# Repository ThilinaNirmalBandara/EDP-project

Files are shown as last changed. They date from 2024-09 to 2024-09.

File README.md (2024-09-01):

This is about our 2nd semester engineering design project at the University of Moratuwa, Faculty of Electronic and Telecommunication Engineering.
We have designed a mini portable UPS that can output 9 V and 12 V simultaneously. Key features include a battery level indicator, mode indicator, 
and automatic switching between power modes.

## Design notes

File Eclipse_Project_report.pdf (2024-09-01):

# Mini UPS for WiFi Routers

## By Team ECLIPSE

# Contents

Contents | 1

1

## 1.Project Description

Our project aims to develop a mini-uninterruptible power supply (UPS) specifically designed for WiFi routers. This mini UPS will ensure uninterrupted internet connectivity during power outages by providing backup power to the router. Additionally, it will include features such as battery level indication and a charging indicator.

Main features

- Backup Power for WiFi Routers: The mini UPS will provide backup power to WiFi routers during power outages, ensuring uninterrupted internet connectivity up to 6 hours.
- Battery Level Indication: A built-in battery level indicator will display the remaining battery capacity, allowing users to monitor the UPS’s status and plan accordingly.
- LED Indicator: The UPS will include LED indicators to notify users whether the output is connected to main power or battery power.

## 2.Technical Feasibility

Input Voltage

- 12V DC

Output Voltage

- 9V / 12V DC

Voltage Regulation

- Buck Converter: Reduces input voltage to 8.5 V for battery charging.
- Boost Converter: Steps up voltage to 12V output.
- Additional Buck Converter: Provides 9V output.

Charging Functionality

- Utilizes buck converter to regulate input voltage to 8.5 V for charging the battery pack.
- Utilizes a BMS board to ensure safety of battery pack.

Battery Pack

- Capacity: 6400 mAh 7.4 V
- Configuration: 2 series 2 parallel (3200 mAh 3.7 V each)
- Charging Method: Constant voltage charging with current limiting

Components specification

- IRF9530 power MOSFET: Fast swithcing action
- 1N5822 diodes : Over voltage protection(Peak Reverse voltage 40 V) , Low forward voltage drop (0.525 V) , High frequency operation , Low power loss

Conversion Efficiency

- Greater than 90%
Mini UPS | 2 | ECLIPSE

Protection Features

- Overvoltage Protection
- Overcurrent Protection
- Reverse Polarity Protection

Dimensions

- 12cm x 9cm x 6cm [Length x Width x Height]

Enclosure Material

- PLA

Indicator LEDs

- AC Power mode indicator
- Battery mode indicator
- Battery level indicator

Connectors

- Input: DC female barrel jack (5.5 x 2.5 mm)
- Output: 2 x DC female barrel jack (5.5 x 2.5 mm)

## 3.Product Architecture

Input

- Would be taken from the 12V adapter.
- Is directly connected to the buck converter that steps down the voltage to 8.5V.

Output

- Depending on the user’s requirement, output can be taken as either 9V or 12V.
- Would be taken from the Buck-Boost converter.
- 12V - From the Boost converter.
- 9V - Above 12V will be further stepped down and taken from the Buck converter.

Indicators

- Two LEDs - Indicate the mode the UPS is working on (Direct mode or using the battery).
- LED screen - Indicates the battery level of the UPS.
Mini UPS | 3 | ECLIPSE

How to Work with this UPS

- **Powering the UPS:**

– Use the adapter that comes with your WiFi router.

– Plug the adapter into the input of the UPS.

– Use the male-to-male DC cable provided to connect the output of the UPS to your router.

- **Dual Router Setup:**

– If you need to power two routers simultaneously, use a separate adapter that provides at least 3A of current as the input to the UPS.

- **Front Panel Indicators:**

– The green LED indicates that the UPS is in battery mode.

– The red LED indicates that the UPS is in mains power mode.

– The LED screen displays the current battery level.

- **Switches:**

– The switch located at the bottom of the LED screen allows you to turn the screen on and off.

– The main switch controls the power output of the UPS, turning it on or off as needed.

## 4.Schematic

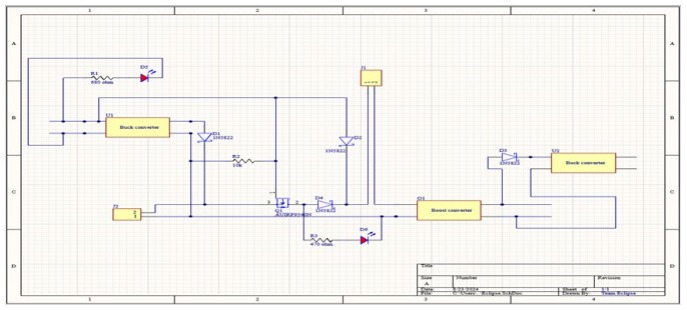
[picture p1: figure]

## 5.Sketches of the Product Enclosure

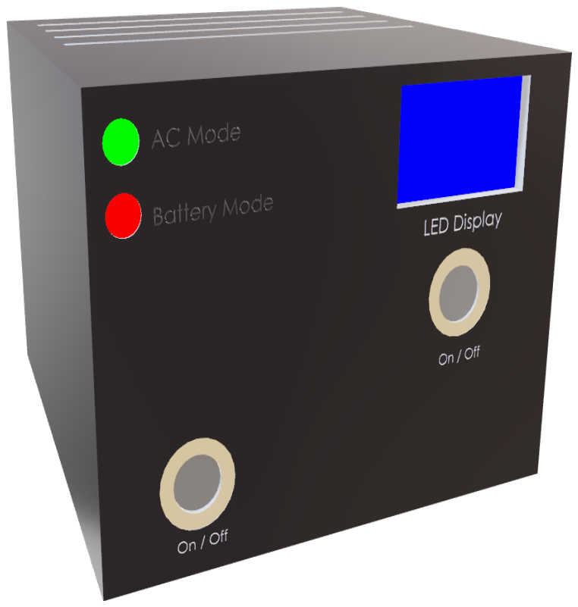
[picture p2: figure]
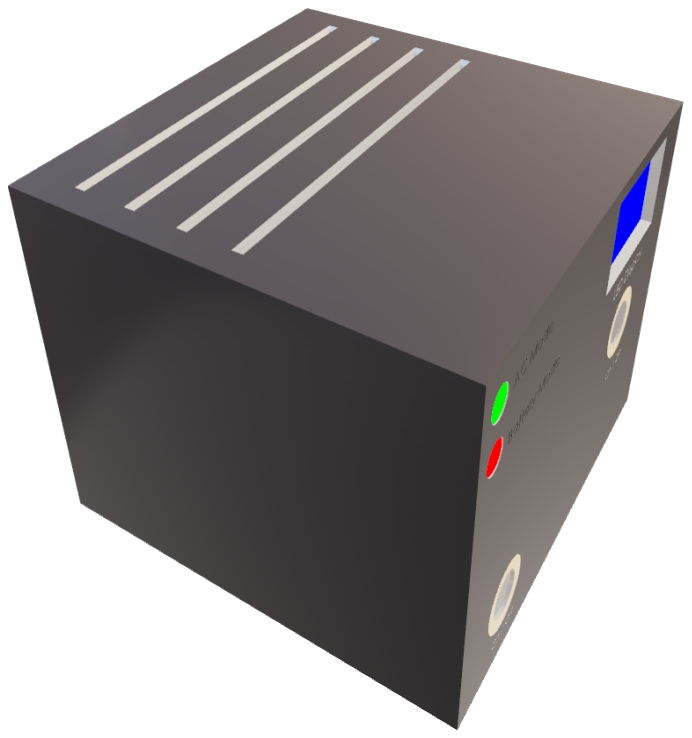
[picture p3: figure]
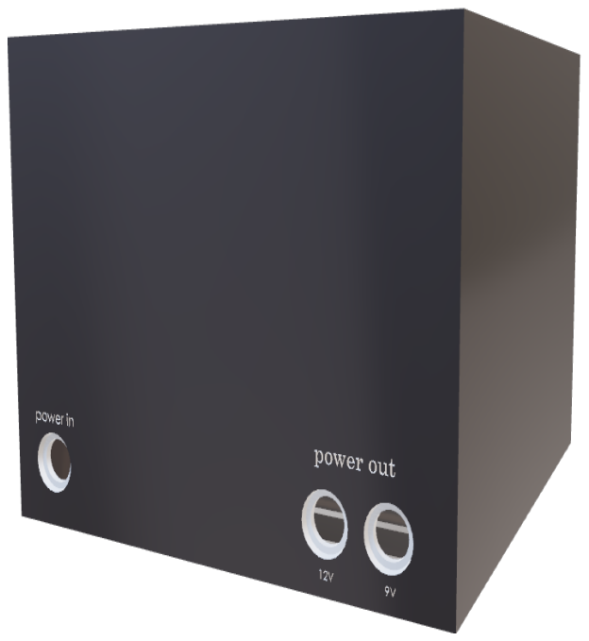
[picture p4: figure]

Mini UPS | 4 | ECLIPSE

## 6.PCB Design

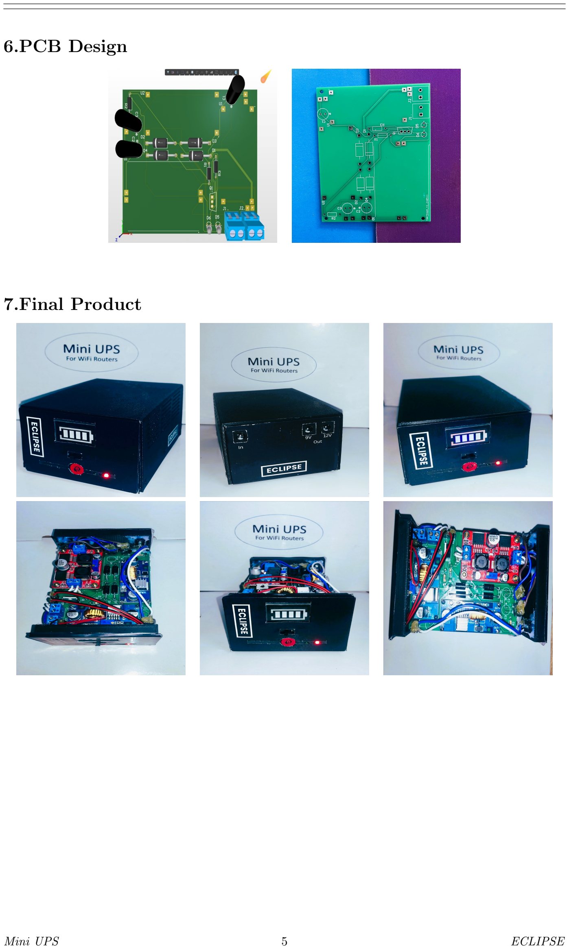
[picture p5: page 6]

## 7.Final Product

Mini UPS | 5 | ECLIPSE

## 8.Project Budget

Component | Description | Unit price | Price
Buck converter * 2 | Xl4015 | Rs.320.00 | Rs.640.00
Boost converter | LM2596 LM2577 | Rs.1120.00 | Rs.1120.00
BMS module | 2s,5A | Rs.230.00 | Rs.230.00
Batteries * 4 | 3.7V , 3200mAh | Rs.600.00 | Rs.2400.00
Other components | diodes, MOSFET, Resistors, LEDs | | Rs.600.00
Enclosure | | | Rs.3280.00
PCB | | | Rs.770.00

Total Product Cost: Rs.9040.00 Profit margin: 4.8%
Price of the Product: Rs.9500.00

## 9.Marketing, Sales, and After Sales

Marketing Approach

Our marketing approach focuses on three key strategies:

- Finding Partners: We will collaborate with internet service providers (ISPs) and electronics retailers to bundle the mini UPS with new router installations. This partnership strategy aims to expand our market reach and ensure that our product reaches customers who need it the most.
- Targeted Messaging: We will craft tailored marketing messages that emphasize the mini UPS’s ability to keep WiFi routers running during power outages. Our communication will address specific pain points such as lost productivity, interrupted online learning, or disrupted streaming services, ensuring our message resonates with our target audience.
- Omnichannel Approach: To maximize product visibility and accessibility, we will leverage a mix of online and offline sales channels. This includes e-commerce platforms, social media campaigns, and partnerships with electronics stores. Additionally, we will offer online demos and tutorials to highlight the product’s benefits and ease of use.

Sales Strategy

Our sales strategy will be centered around building a strong presence in both online and offline markets. We will offer competitive pricing and work closely with our partners to ensure our mini UPS is available where customers are most likely to purchase WiFi routers.

After Sales Support

We are committed to providing excellent after-sales support, including a comprehensive warranty, easy access to customer service, and a clear return policy. We will also offer technical support to assist customers with installation and troubleshooting, ensuring a positive user experience and long-term customer satisfaction.

Mini UPS | 6 | ECLIPSE

## 10.Task Allocation and Our Team

- Bandara I.W.T.N 220061H:

– Circuit Design and PCB Layout

– Assembly and Testing

- Senaweera S.A.H.D 220596C:

– Enclosure Design and 3D Printing – Assembly and Testing

- Fernando D.S 220163X:

– PCB design (Altium)

– Documentation and Report Writing

- Wijenayaka M.B.T.I 220711D:

– Marketing and Sales Strategy

– Enclosure Design and 3D Printing

Mini UPS | 7 | ECLIPSE

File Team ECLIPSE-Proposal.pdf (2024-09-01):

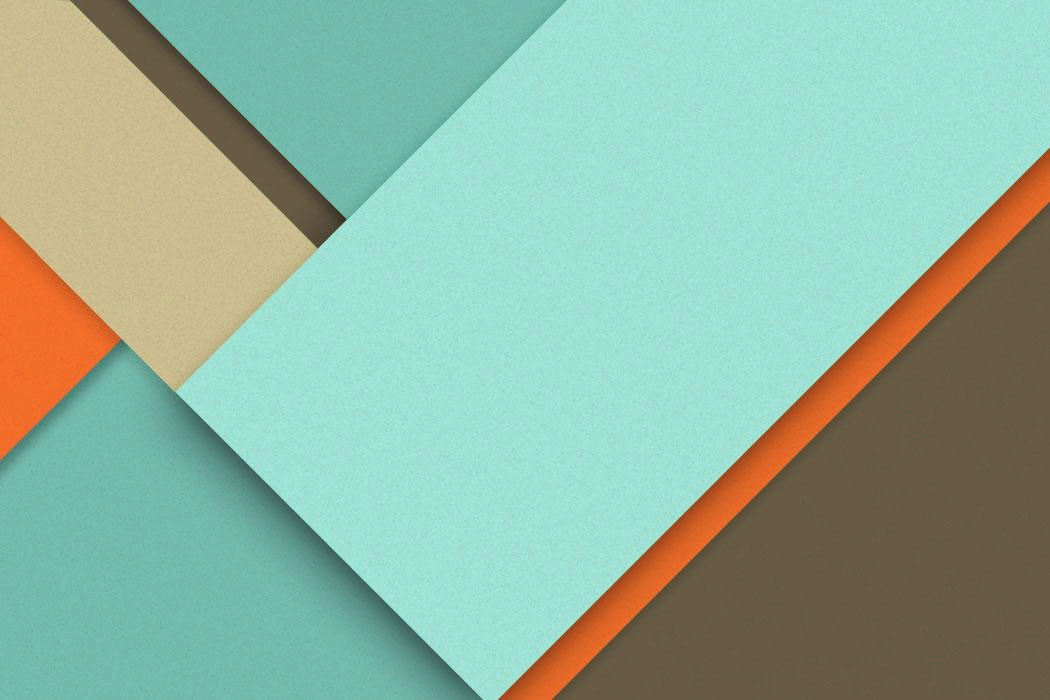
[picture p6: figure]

# MINI UPS FOR WIFI ROUTERS

# Team ECLIPSE

## BANDARA I.W.T.N 220061H WIJENAYAKA M.B.T.I 220711D FERNANDO D.S 220163X SENAWEERA S.A.H.D 220596C

1

## Overview

Our project aims to develop a mini-uninterruptible power supply (UPS) specifically designed for WiFi routers. This mini UPS will ensure uninterrupted internet connectivity during power outages by providing backup power to the router. Additionally, it will include features such as battery level indication, charging indicator, and an intuitive control panel for user convenience.

## Key features

- Backup Power for WiFi Routers: The mini UPS will provide backup power to WiFi routers during power outages, ensuring uninterrupted internet connectivity for users.
- Battery Level Indication: A built-in battery level indicator will display the remaining battery capacity, allowing users to monitor the UPS's status and plan accordingly.
- Charging Indicator: The UPS will feature a charging indicator to notify users when the battery is charging, ensuring that the UPS is always ready for use during power outages.

## Target Audience and Use Cases

- Residential users, small office/home office (SOHO) setups, and remote workers who rely on consistent internet connectivity are the primary target audience.
- Use cases include ensuring uninterrupted internet access for remote work, online learning, entertainment streaming, and smart home automation systems during power outages.

## Market value

With the increasing reliance on internet connectivity for work, education, and entertainment, uninterrupted access to WiFi is crucial for many users. However, power outages can disrupt internet services, leading to frustration and inconvenience. While there are UPS solutions available for larger electronic devices, there is a lack of affordable and tailored options for WiFi routers specifically.
Our mini UPS for WiFi routers aims to fill this gap by providing a cost-effective and efficient solution for maintaining internet connectivity during power outages.
The estimated budget for this project is Rs. 4000, covering the cost of components and development tools.

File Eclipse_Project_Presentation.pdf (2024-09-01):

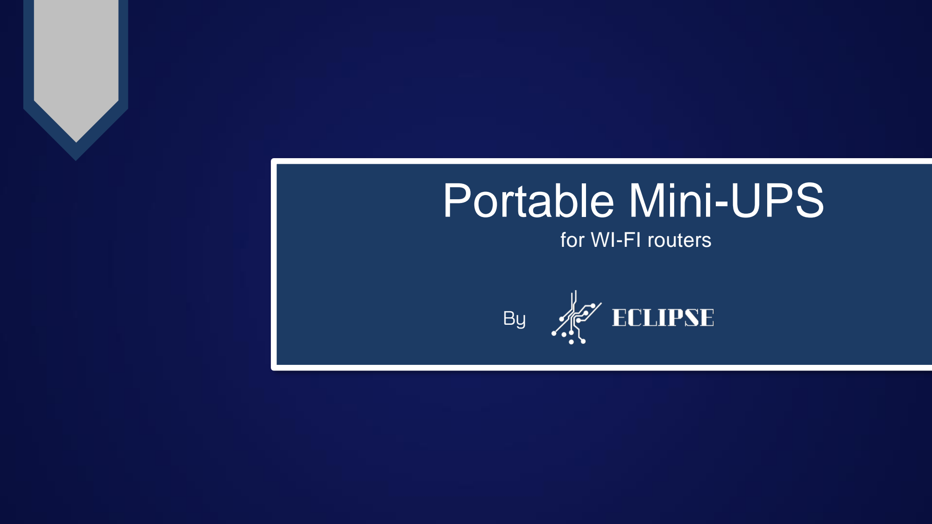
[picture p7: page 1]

# Portable Mini-UPS

## for WI-FI routers

By

## Problem

- Frequent power outages that disrupt internet connectivity.
- Lack of affordable small UPSs in the market that supports Wi-Fi routers that require 9V and 12V voltages.

## Solution

- An affordable mini ups that supports both 9V and 12V Wi-Fi routers.

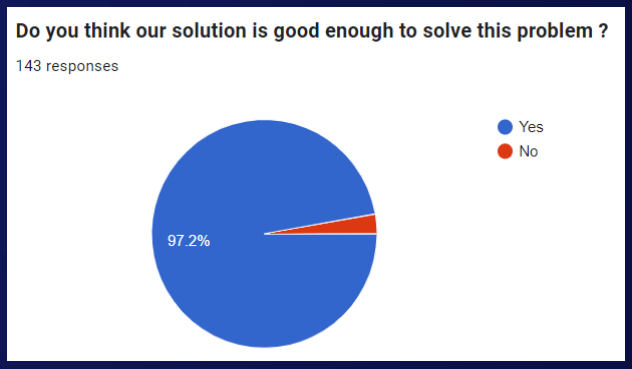
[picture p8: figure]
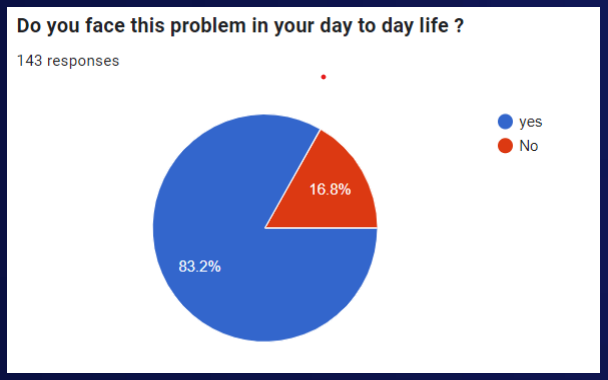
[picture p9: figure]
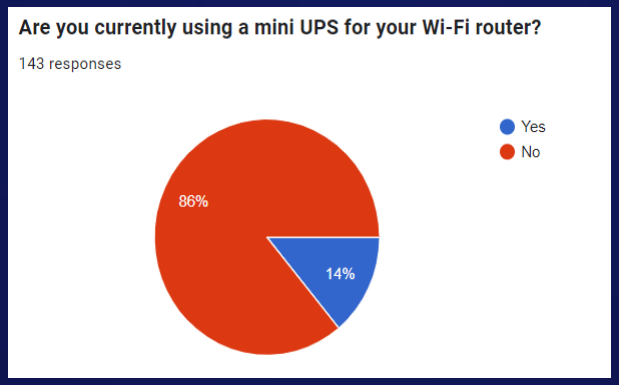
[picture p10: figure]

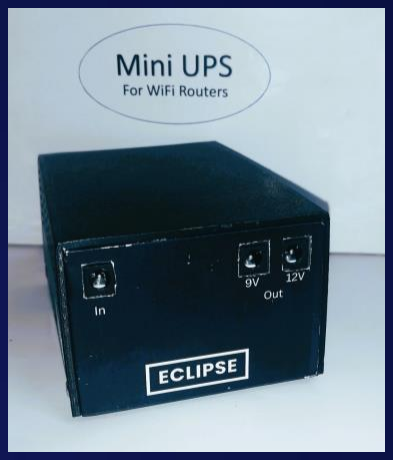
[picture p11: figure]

# Our product

- An affordable ,rechargeable mini-UPS that supports both 9V and 12V Wi-Fi routers.
- Additional features
– Battery level indicator
– Mode indicator

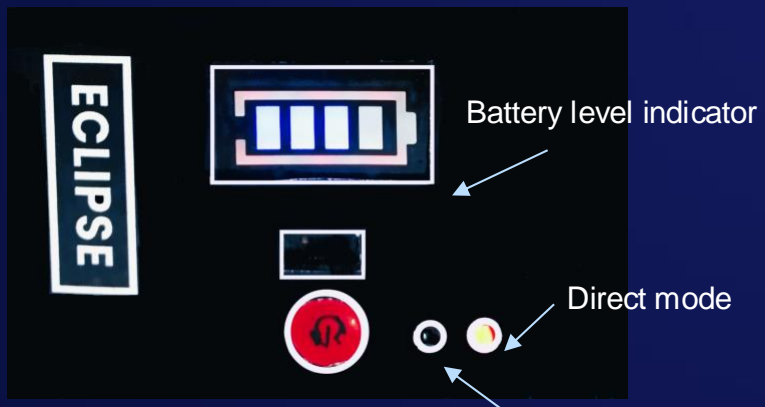
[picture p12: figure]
Battery level indicator; Direct mode
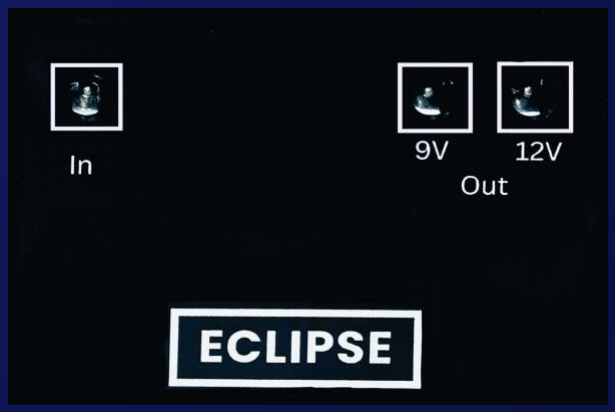
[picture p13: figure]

Front view | Back view
Battery mode

# Why Choose Our Mini UPS?

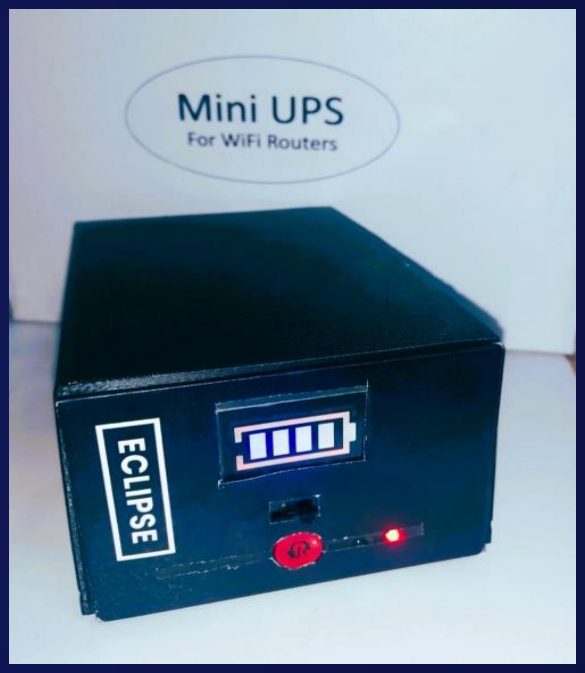
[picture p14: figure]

## - Uninterrupted connectivity : Enjoy up to 6 hours of

continuous internet access during power failures.

## - Compact and Efficient : Small in size but big on performance, with over 90% power conversion

efficiency.

## - User Friendly Features : Includes easy-to-read battery level indicators and seamless switching

between power modes.

## - Versatile Compatibility : Works with a wide range of Wi-Fi routers, making it the perfect addition to any

home or office.

# Perfect for :

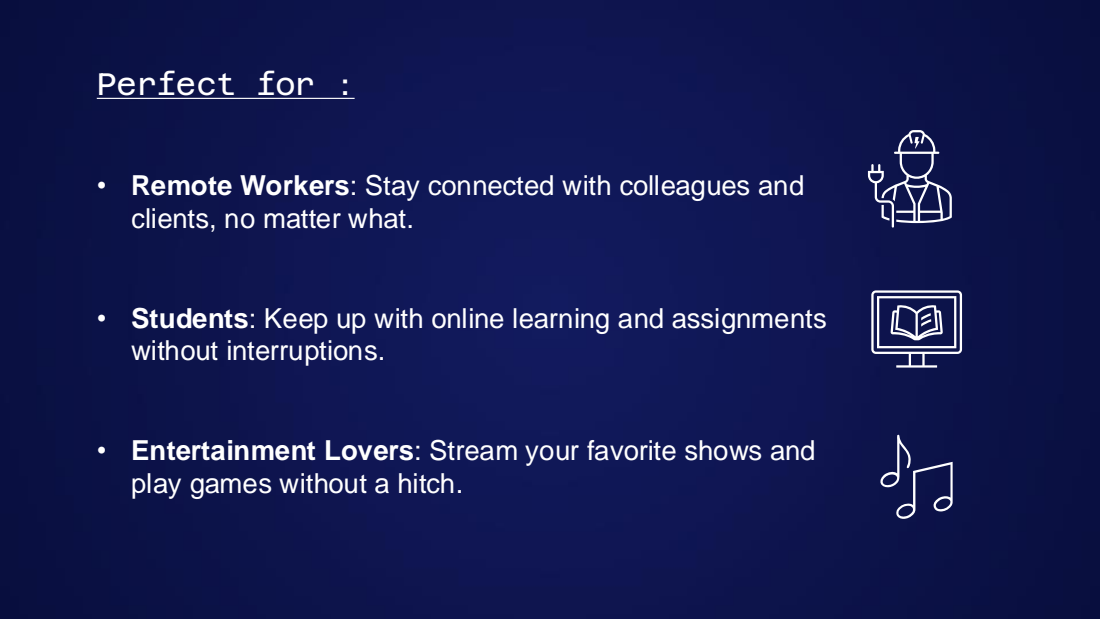
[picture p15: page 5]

• Remote Workers: Stay connected with colleagues and
clients, no matter what.

• Students: Keep up with online learning and assignments
without interruptions.

• Entertainment Lovers: Stream your favorite shows and
play games without a hitch.

# Product Architecture

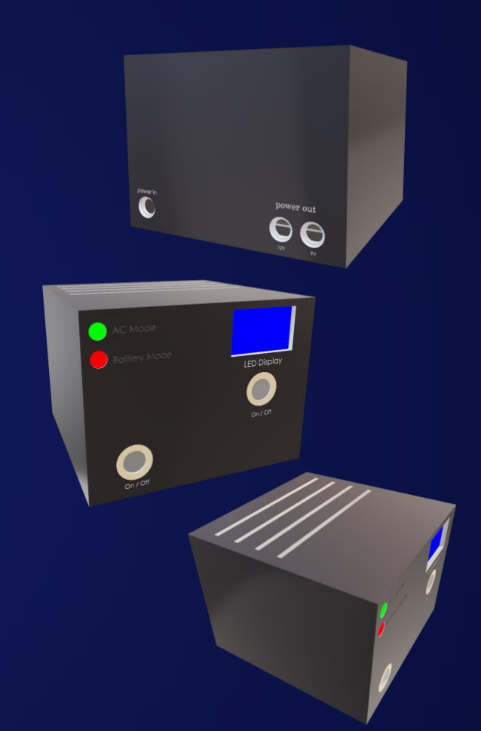
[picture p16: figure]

## Computer Aided Design

INPUT

- Would be taken from the 12V adapter.

OUTPUT

- Depending on the user’s requirement output can be taken as either 9v or 12V.
- Would be taken from the Buck Boost converter.
12V -From the Boost converter.
9V- Above 12V will be further stepped down and taken from the Buck converter.

INDICATORS

- Two LEDs - Indicate the mode the UPS is working on. ( Direct mode or using the battery.)
- LED screen- Indicate the battery level of the UPS.

# Schematic

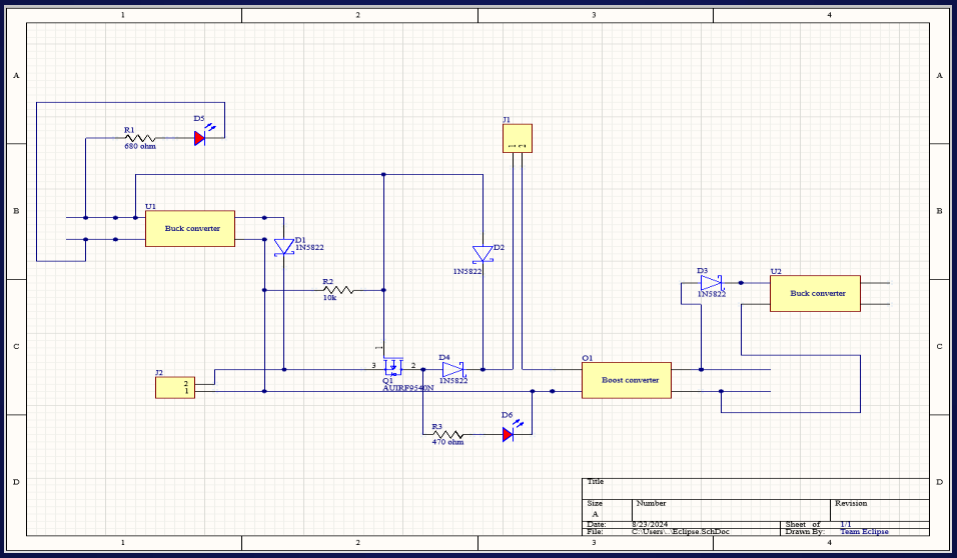
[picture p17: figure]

# PCB design & 3D view

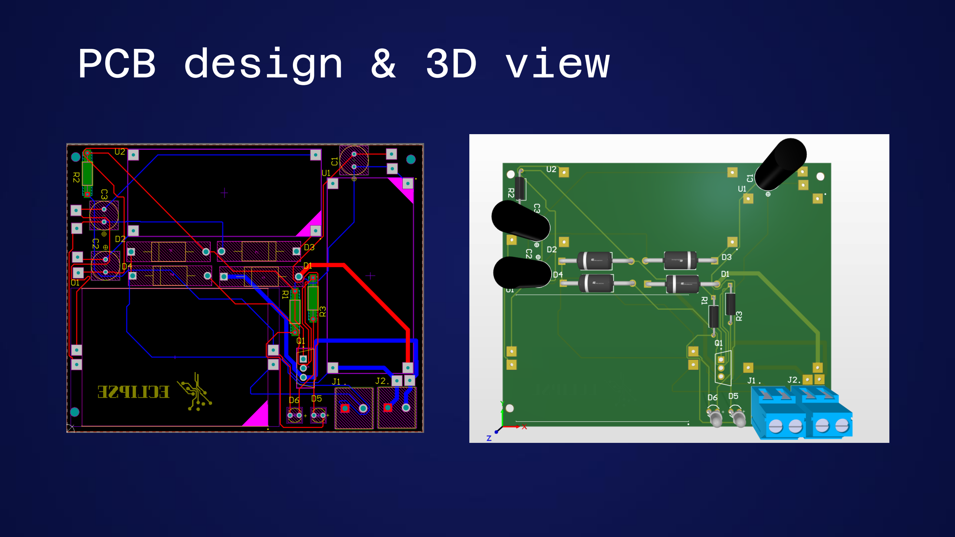
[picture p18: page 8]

# Completed PCB Assembly

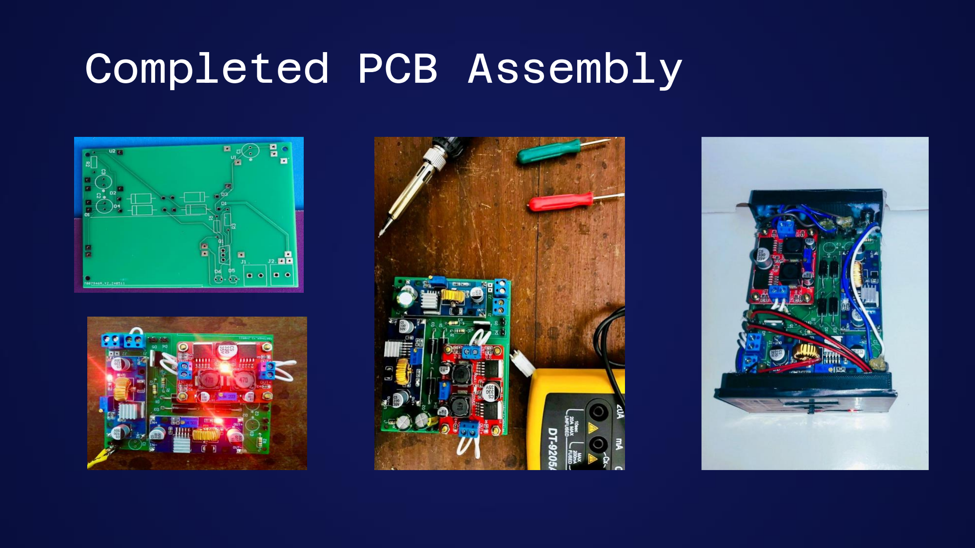
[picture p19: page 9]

# Enclosure

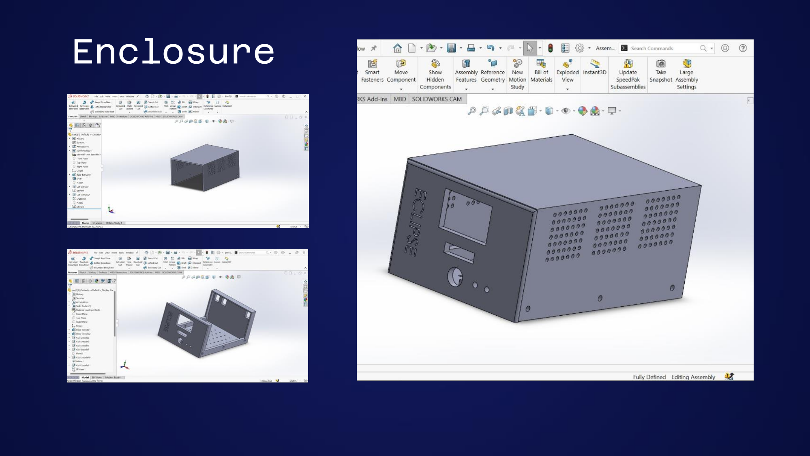
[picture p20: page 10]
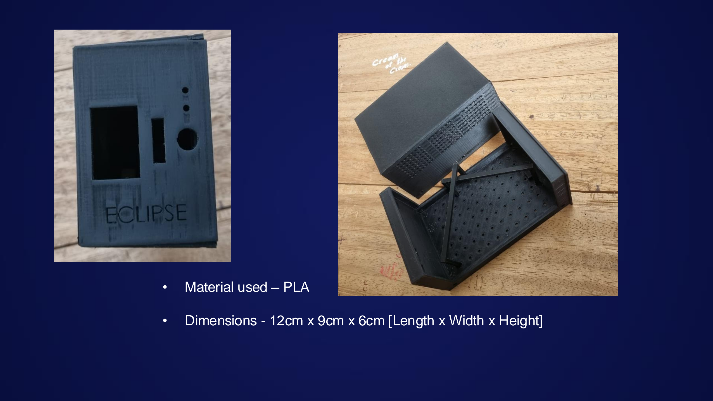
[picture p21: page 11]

- Material used – PLA
- Dimensions - 12cm x 9cm x 6cm [Length x Width x Height]

## Durability

The material effectively
manages heat, safeguarding internal components from
damage. Additionally, It’s electro-inductive properties minimize electric hazards, ensuring safe operation in diverse environments
without interference risks.

## Safety

The 3D-printed material
used for our UPS enclosure is extremely durable,
assuring long-term
dependability and protecting interior components from
wear and tear.

## Simple

Our UPS enclosure,
measuring 12×9×6
centimeters, provides
enough space for
component housing. Its
simplified form provides
easy installation and perfect integration into a variety of settings.

# Product Enclosure

# Final product

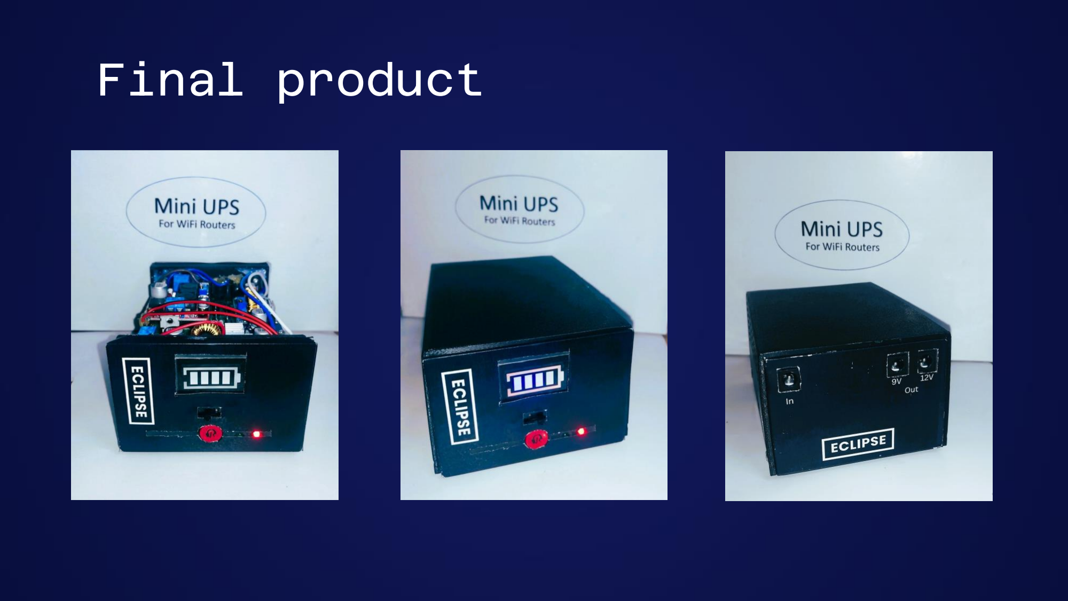
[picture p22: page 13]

# Project expenses

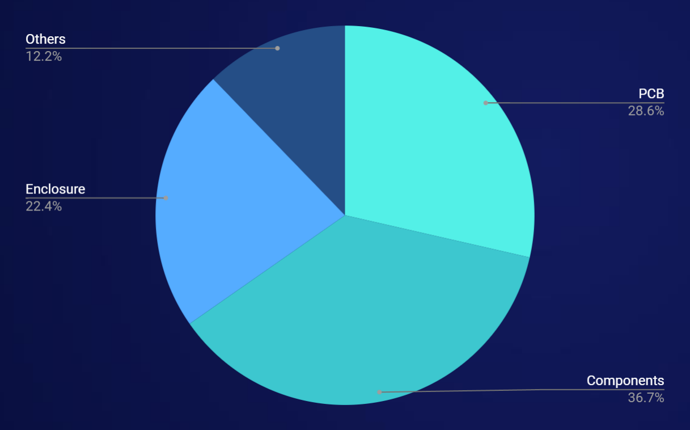
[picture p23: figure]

# PCB

# Components

# Enclosure

# Other

$45

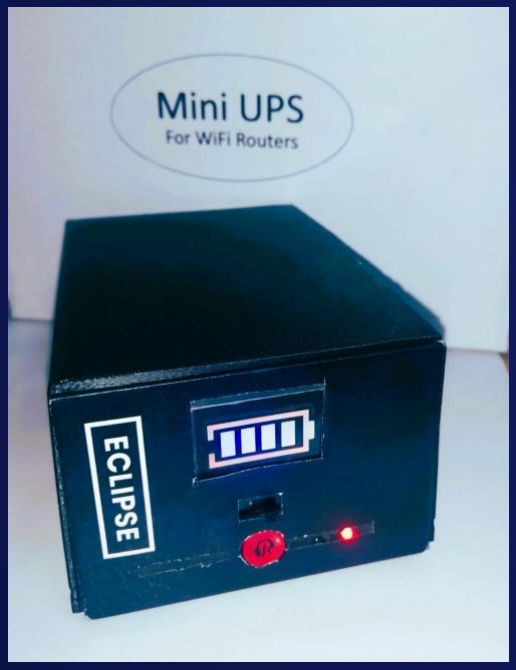
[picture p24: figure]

### (LKR 13500/=)

## Only 12V support UPSs’ Price In Sri Lankan Market

## Avg. Importing Cost Of a Portable UPS

## Value of Our Prototype (Has both 9V,12V outputs With battery level indicator)

# +LKR10000/=

# LKR9000/=

# Market Price

# Marketing Sales and Beyond

Test the product with a group of users to receive feedback and improve the product; Identifying and establishing strategic partnerships with complementary businesses to expand market reach.; Execute a marketing campaign to promote the product to the target audience

## Release the product to the market with a comprehensive launch plan

## Provide customer support to ensure the highest customer satisfaction levels

## Explore opportunities for growth and expansion of the Production

## Continuously improve the UPS based on customer feedback and market trends

# Task Allocation and Our Team

- Bandara I.W.T.N. 220061H: – Circuit Design and PCB Layout – Assembly and Testing
- Senaweera S.A.H.D. 220596C: – Enclosure Design and 3D Printing – Assembly and Testing
- Fernando D.S. 220163X:
– PCB design (Altium)
– Documentation and Report Writing
- Wijenayaka M.B.T.I. 220711D: – Marketing and Sales Strategy
– Enclosure Design and 3D Printing

# Thank You!

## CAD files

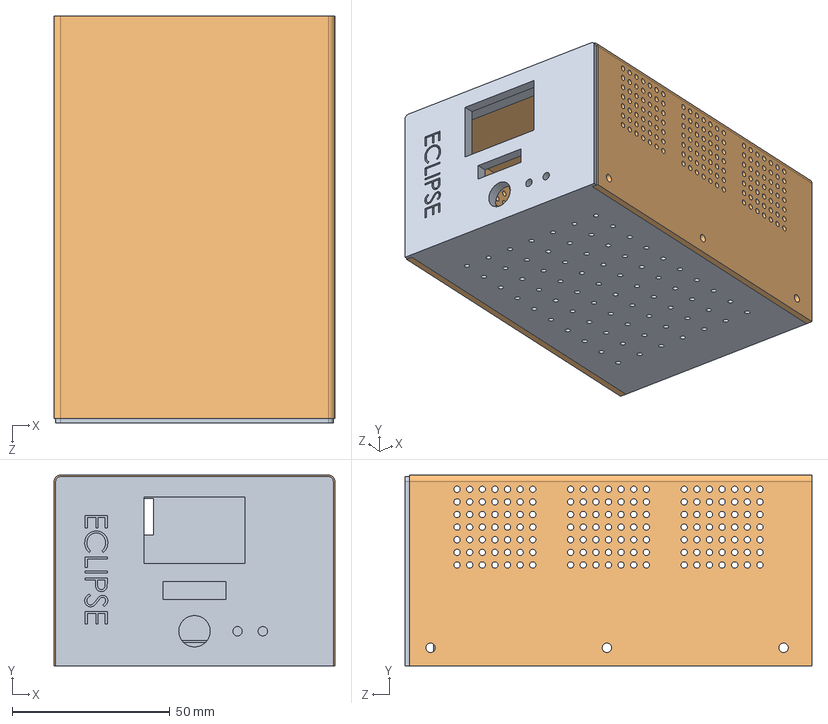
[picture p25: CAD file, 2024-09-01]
Enclosure/Assemble_final.SLDASM
89.0 x 60.5 x 129.0 mm
Part2(New)

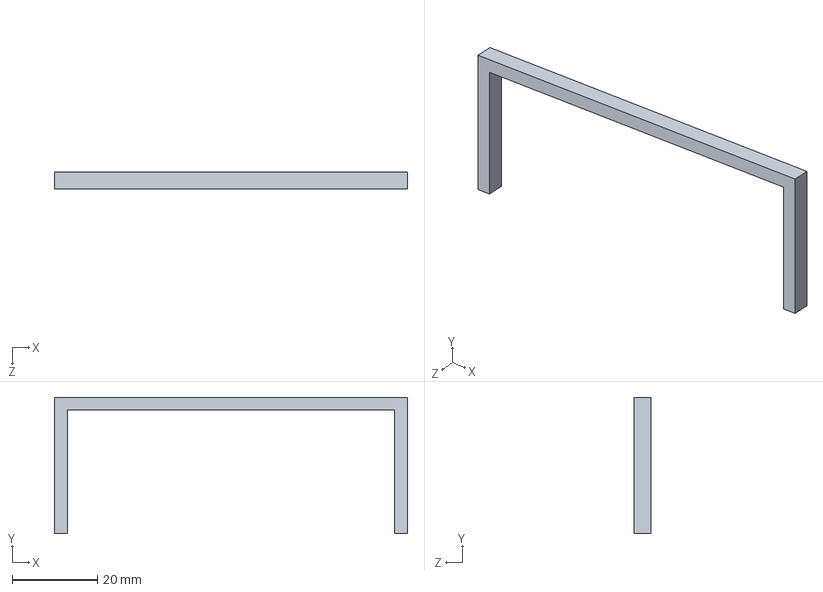
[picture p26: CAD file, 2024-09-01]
Enclosure/Part3.SLDPRT
83.0 x 32.0 x 4.00 mm

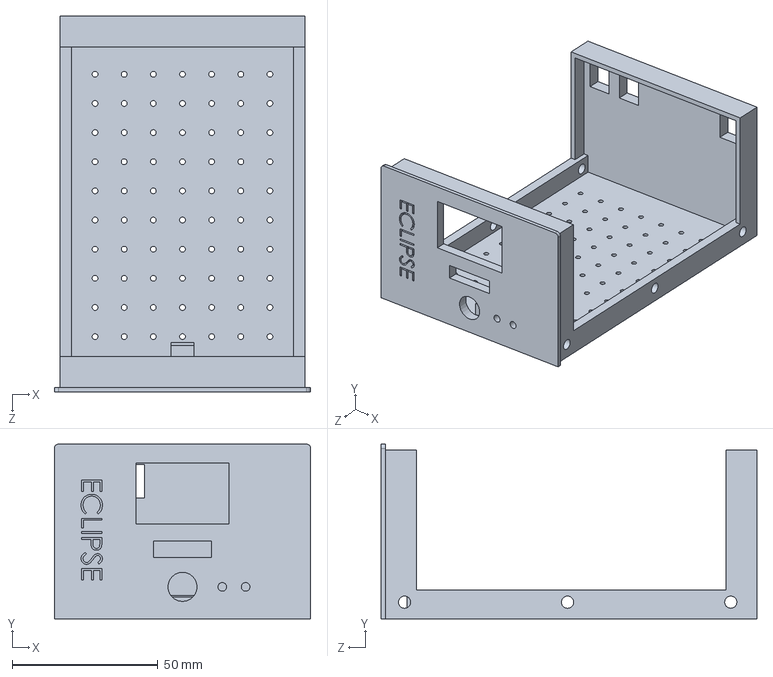
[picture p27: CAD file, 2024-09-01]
Enclosure/part1.SLDPRT
88.0 x 60.0 x 129.0 mm

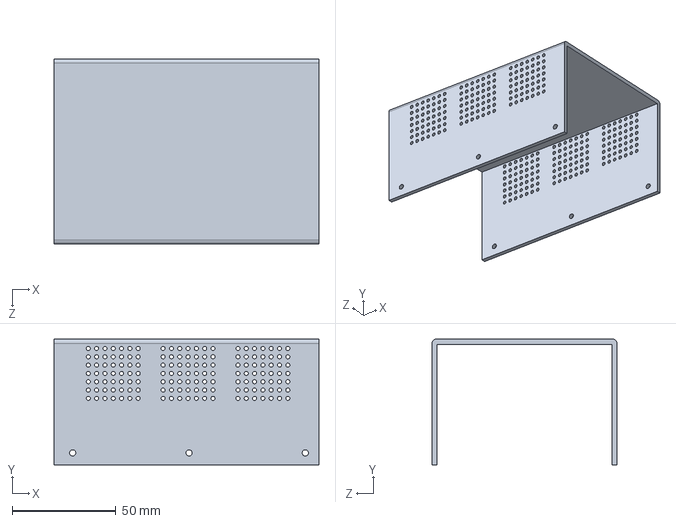
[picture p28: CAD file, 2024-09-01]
Enclosure/Part2(New).SLDPRT
127.5 x 60.5 x 89.0 mm
